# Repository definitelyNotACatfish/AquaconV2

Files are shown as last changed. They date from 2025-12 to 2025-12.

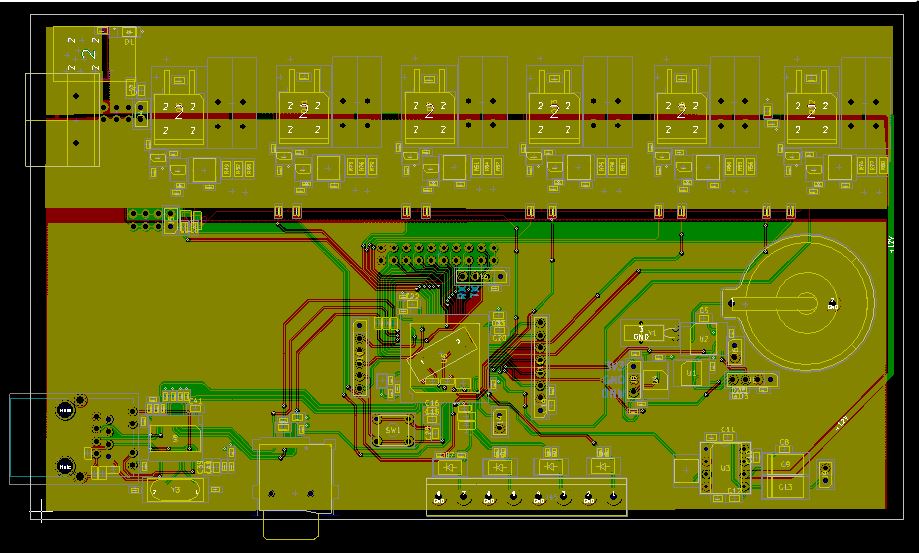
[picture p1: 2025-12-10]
SDCard/WEBSERV/PICTURE/WEBSERV.JPG

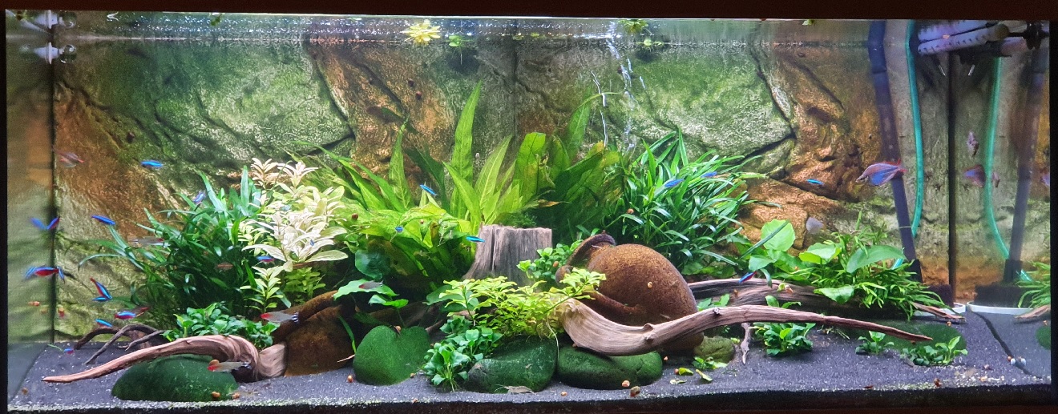
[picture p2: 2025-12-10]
SDCard/WEBSERV/PICTURE/AQUARIUM.JPG

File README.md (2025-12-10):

# Web based Aquarium LED controller
I didn't want to pay 200€ to buy a 6 channel LED PWM controller. So I invested 400€ and a half year to build it myself :)

## Keyfeatures
- 6 channels PWM controlled (For LEDs and other stuff like CO2 relay or PC fan to cool water surface
- Web based interface to set up channel independent scenarious
- Temperature controlled water surface cooling (Really cool in summer)
- SD card bootloader and ethernet based file transfer to SD card

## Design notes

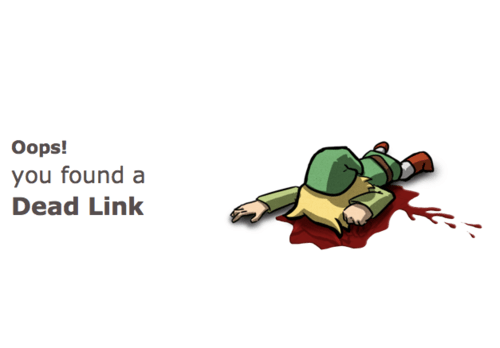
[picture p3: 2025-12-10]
SDCard/WEBSERV/PICTURE/DEADLINK.PNG

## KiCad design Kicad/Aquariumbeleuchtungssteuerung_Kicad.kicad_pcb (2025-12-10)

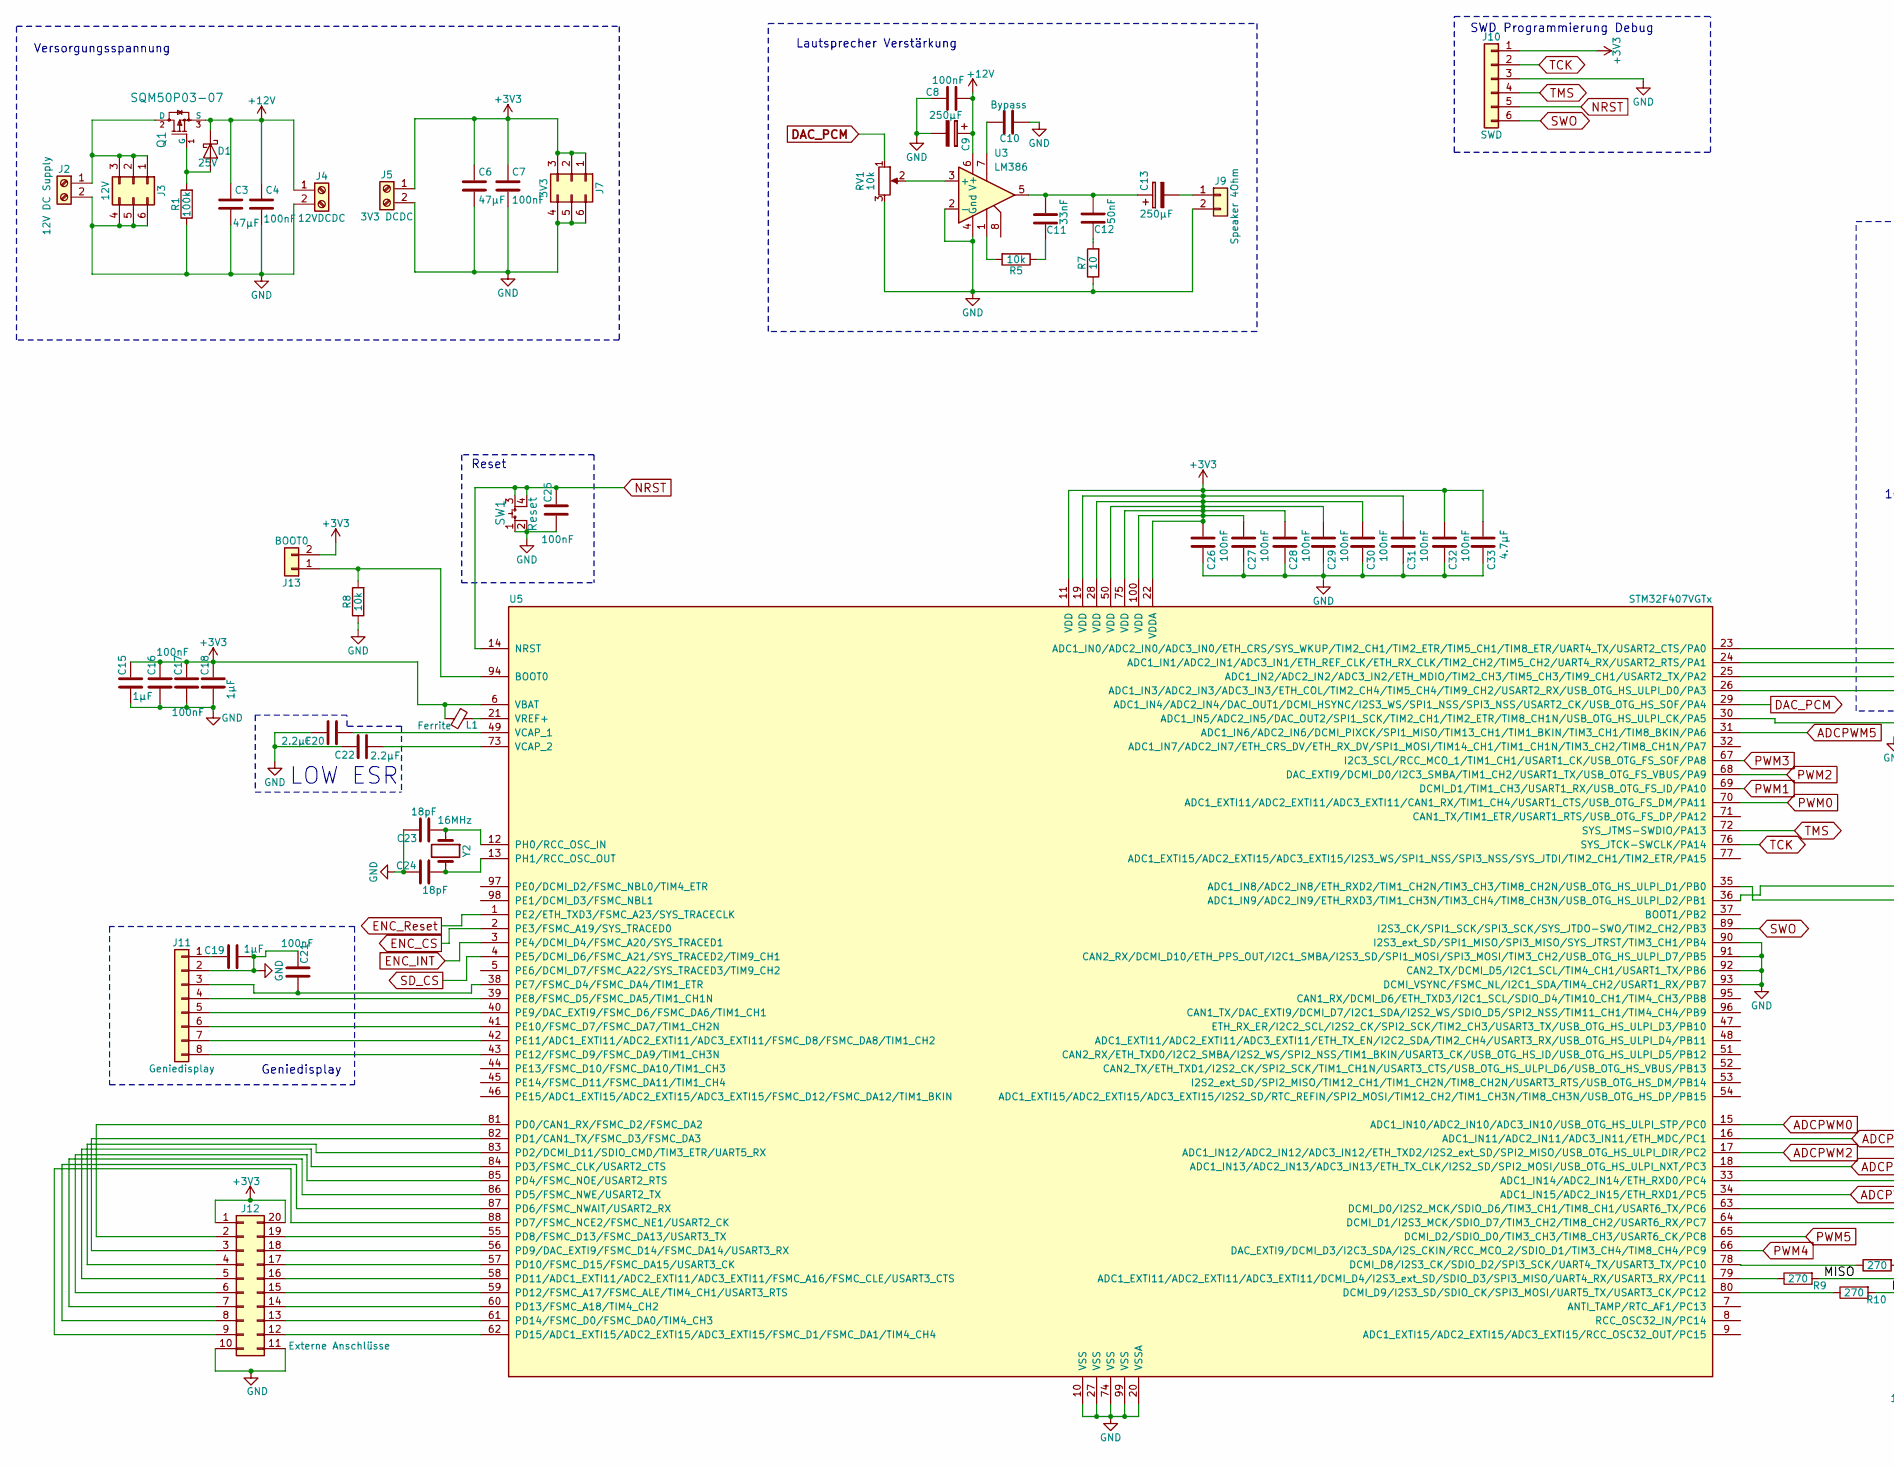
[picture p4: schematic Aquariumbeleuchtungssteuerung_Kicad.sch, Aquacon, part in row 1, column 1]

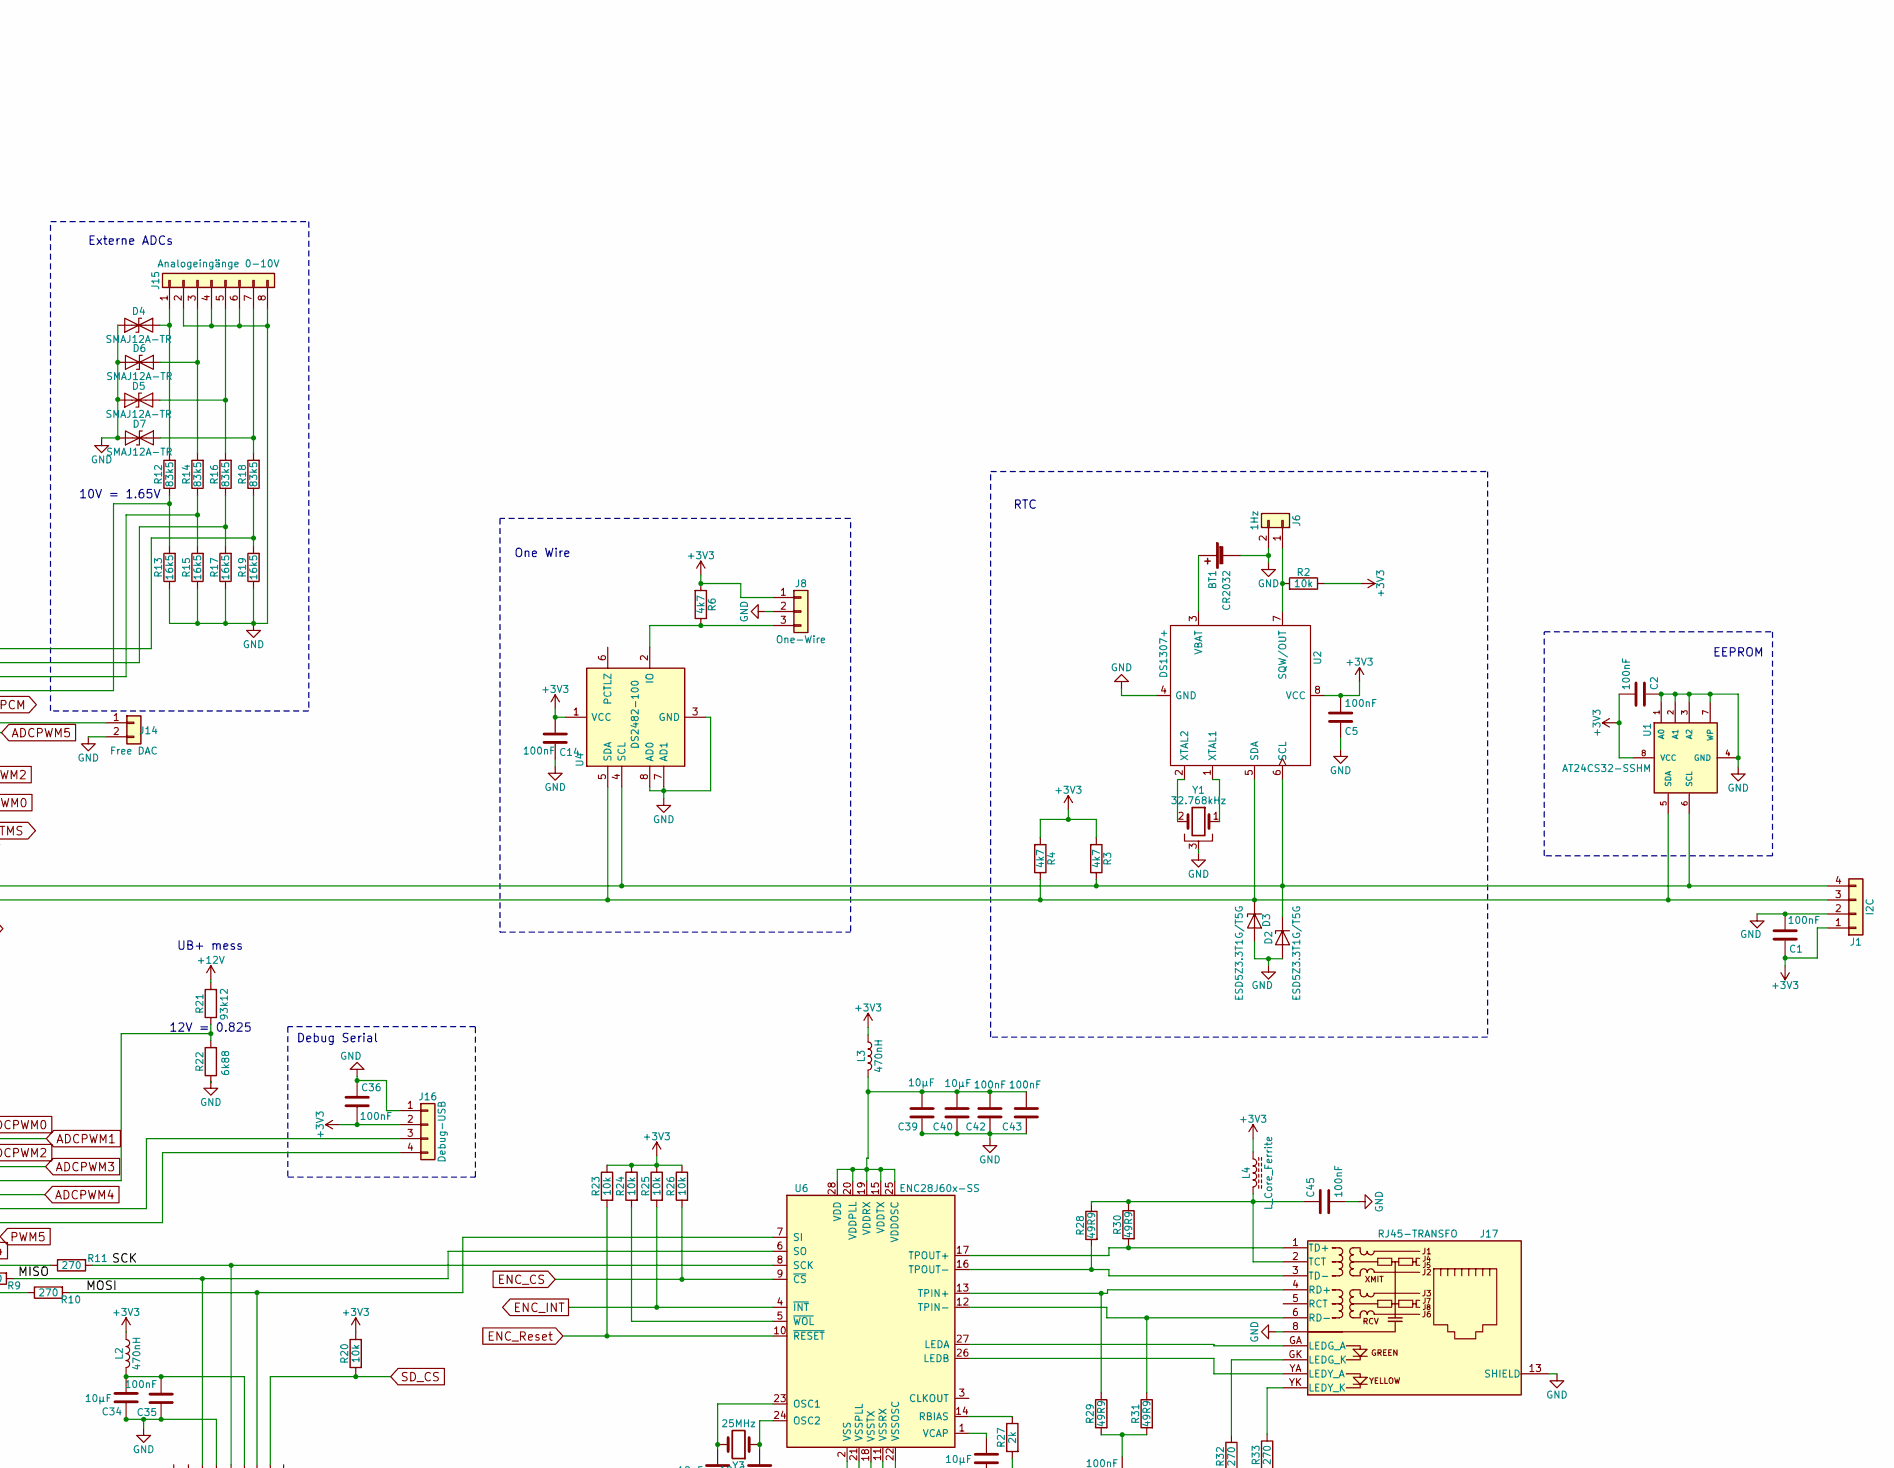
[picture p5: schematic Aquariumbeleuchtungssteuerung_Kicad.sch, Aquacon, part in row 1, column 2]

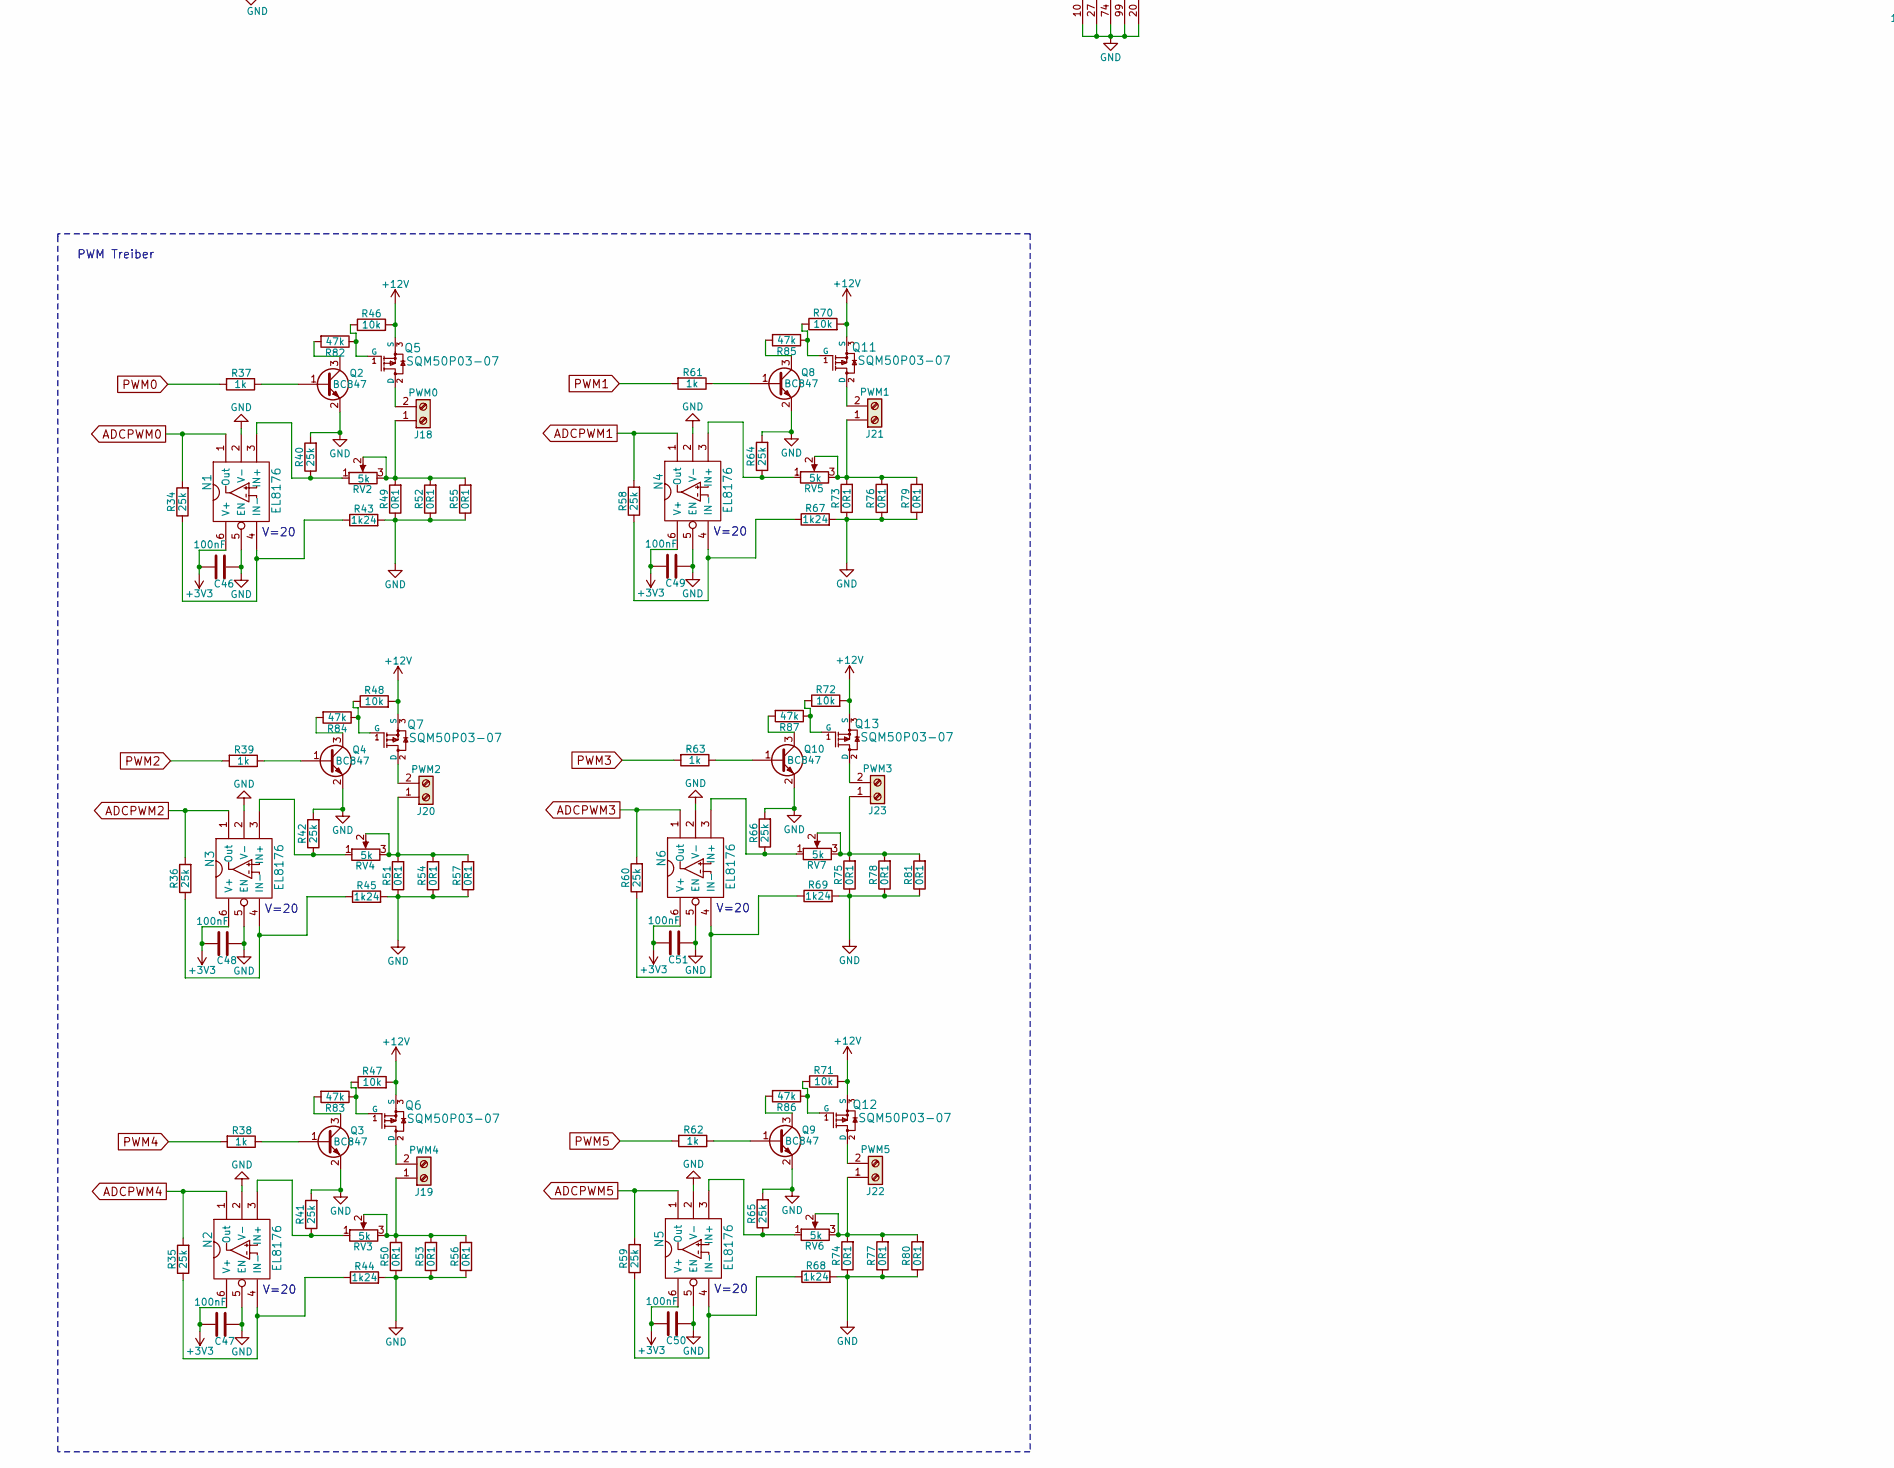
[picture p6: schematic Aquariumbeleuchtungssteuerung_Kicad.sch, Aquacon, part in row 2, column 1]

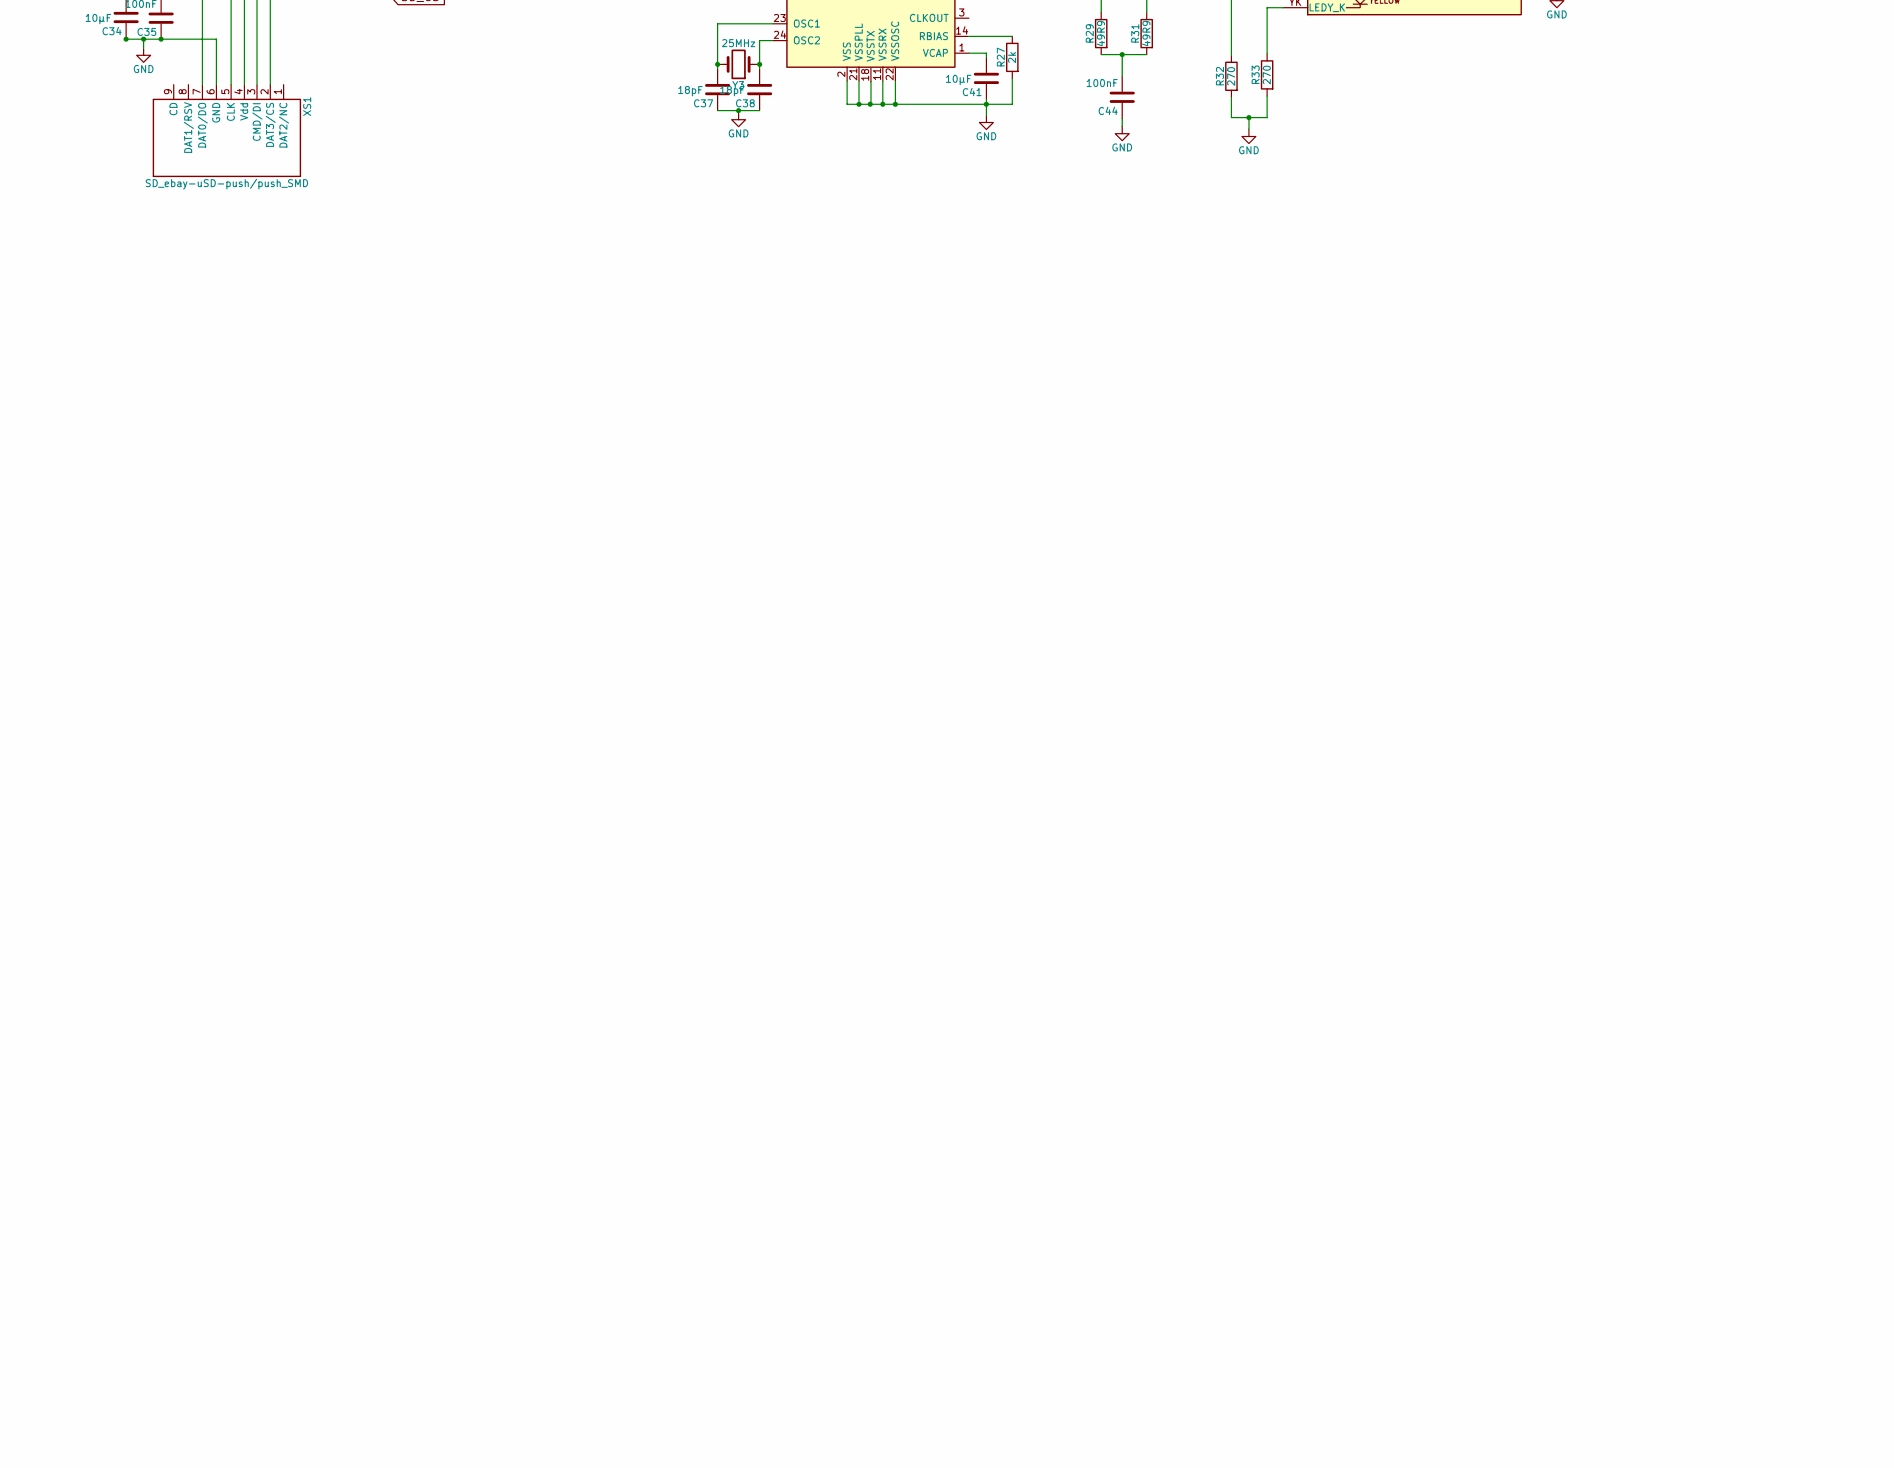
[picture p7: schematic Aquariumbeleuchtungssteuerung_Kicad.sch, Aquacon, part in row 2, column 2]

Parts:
BT1: CR2032; Keystone_105_1x2430-CoinCell
C1, C2, C14, C21, C26, C27, C28, C29, C30, C31, C32, C36, C42, C43, C44, C45, C46, C47, C48, C49, C50, C51: 100nF; C_0603
C3, C6: 47µF; R_1206
C4, C5, C7, C8, C16, C17, C25: 100nF; C_0805
C9, C13: 250µF; CP_Tantalum_Case-X_EIA-7343-43_Reflow
C10: Bypass; C_0805
C11: 33nF; C_0805
C12: 50nF; C_0805
C15, C18, C19: 1µF; C_0805
C20, C22: 2.2µF; C_0805
C23, C24, C37, C38: 18pF; C_0603
C33: 4.7µF; C_0805
C34: 10µF; L_0805
C35: 100nF; L_0603
C39, C40, C41: 10µF; C_0805
D1: 25V; D_SOD-123
D2, D3: ESD5Z3.3T1G/T5G; D_SOD-523
D4, D5, D6, D7: SMAJ12A-TR; D_SMA
J1: I2C; Pin_Header_Straight_1x04_Pitch2.54mm
J2: 12V DC Supply; DECA_MB91_9.52mm_01X02
J3: 12V; Stiftleiste-2x3x2.54mm
J4: 12VDCDC; Pin_Header_Straight_1x02_Pitch2.54mm
J5: 3V3 DCDC; Pin_Header_Straight_1x02_Pitch2.54mm
J6: 1Hz; Pin_Header_Straight_1x02_Pitch2.54mm
J7: 3V3; Stiftleiste-2x3x2.54mm
J8: One-Wire; Pin_Header_Straight_1x03_Pitch2.54mm
J9: Speaker 4Ohm; Pin_Header_Straight_1x02_Pitch2.54mm
J10: SWD; Pin_Header_Straight_1x06_Pitch2.54mm
J11: Geniedisplay; Pin_Header_Straight_1x08_Pitch2.54mm
J12: Externe Anschlüsse; Stiftleiste_02x10
J13: BOOT0; GS2
J14: Free DAC; Pin_Header_Straight_1x02_Pitch2.54mm
J15: Analogeingänge 0-10V; TerminalBlock_bornier-8_P5.08mm
J16: Debug-USB; Pin_Header_Straight_1x04_Pitch2.54mm
J17: RJ45-TRANSFO; RJ45_TRANSFO
J18: PWM0; Phoenix-D-FRONT-2.5Vx2
J19: PWM4; Phoenix-D-FRONT-2.5Vx2
J20: PWM2; Phoenix-D-FRONT-2.5Vx2
J21: PWM1; Phoenix-D-FRONT-2.5Vx2
J22: PWM5; Phoenix-D-FRONT-2.5Vx2
J23: PWM3; Phoenix-D-FRONT-2.5Vx2
L1: Ferrite; L_0805
L2: 470nH; L_0805
L3: 470nH; L_0603
L4: L_Core_Ferrite; L_0603
N1, N2, N3, N4, N5, N6: EL8176; SOT-23-6_Handsoldering
Q1, Q5, Q6, Q7, Q11, Q12, Q13: SQM50P03-07; TO-263-2
Q2, Q3, Q4, Q8, Q9, Q10: BC847; SOT-23
R1: 100k; R_0805
R2, R8, R20, R23, R24, R25, R26: 10k; R_0603
R3, R4, R6: 4k7; R_0603
R5, R46, R47, R48, R70, R71, R72: 10k; R_0805
R7: 10; R_0805
R9, R10, R11, R32, R33: 270; R_0603
R12, R14, R16, R18: 83k5; R_0603
R13, R15, R17, R19: 16k5; R_0603
R21: 93k12; R_0805
R22: 6k88; R_0805
R27: 2k; R_0603
R28, R29, R30, R31: 49R9; R_0603
R34, R35, R36, R40, R41, R42, R58, R59, R60, R64, R65, R66: 25k; R_0603
R37, R38, R39, R61, R62, R63: 1k; R_0603
R43, R44, R45, R67, R68, R69: 1k24; R_0603
R49, R50, R51, R52, R53, R54, R55, R56, R57, R73, R74, R75, R76, R77, R78, R79, R80, R81: 0R1; R_1206
R82, R83, R84, R85, R86, R87: 47k; R_0603
RV1: 10k; Potentiometer_Trimmer_Bourns_3224J
RV2, RV3, RV4, RV5, RV6, RV7: 5k; Potentiometer_Trimmer_Bourns_3224J
SW1: Reset; SW_TH_Tactile_Omron_B3F-10xx
U1: AT24CS32-SSHM; SOIC-8_3.9x4.9mm_Pitch1.27mm
U2: DS1307+; SO-8_5.3x6.2mm_Pitch1.27mm
U3: LM386; DIP-8_W7.62mm_Socket
U4: DS2482-100; SOIC-8_3.9x4.9mm_Pitch1.27mm
U5: STM32F407VGTx; LQFP-100_14x14mm_Pitch0.5mm
U6: ENC28J60x-SS; SSOP-28_5.3x10.2mm_Pitch0.65mm
XS1: SD_ebay-uSD-push/push_SMD; Conn_uSDcard
Y1: 32.768kHz; Crystal_C38-LF_d3.0mm_l8.0mm_Horizontal_1EP_style2
Y2: 16MHz; Crystal_SMD_HC49-SD
Y3: 25MHz; Crystal_SMD_HC49-SD

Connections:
+3V3: C1.1, C2.2, C5.2, C6.1, C7.1, C14.2, C15.1, C16.1, C17.1, C18.1, C26.2, C27.2, C28.2, C29.2, C30.2, C31.2, C32.2, C33.2, C36.2, C46.2, C47.2, C48.2, C49.2, C50.2, C51.2, J1.1, J5.1, J7.1, J7.2, J7.3, J8.1, J10.1, J12.1, J12.20, J13.2, J16.2, L1.2, L2.1, L3.1, L4.1, N1.6 (V+), N2.6 (V+), N3.6 (V+), N4.6 (V+), N5.6 (V+), N6.6 (V+), R2.1, R3.2, R4.2, R6.2, R20.1, R23.1, R24.1, R25.1, R26.1, U1.8 (VCC), U2.8 (VCC), U4.1 (VCC), U5.6 (VBAT), U5.11 (VDD), U5.19 (VDD), U5.22 (VDDA), U5.28 (VDD), U5.50 (VDD), U5.75 (VDD), U5.100 (VDD)
+12V: C3.1, C4.1, C8.1, C9.1, D1.1 (K), J4.1, Q1.3 (S), Q5.3 (S), Q6.3 (S), Q7.3 (S), Q11.3 (S), Q12.3 (S), Q13.3 (S), R21.2, R46.2, R47.2, R48.2, R70.2, R71.2, R72.2, U3.6 (V+)
/MISO: R9.2, U6.6 (SO), XS1.7 (DAT0/DO)
/MOSI: R10.2, U6.7 (SI), XS1.3 (CMD/DI)
/SCK: R11.2, U6.8 (SCK), XS1.5 (CLK)
ADCPWM0: N1.1 (Out), R34.2, U5.15 (ADC1_IN10/ADC2_IN10/ADC3_IN10/USB_OTG_H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)
ADCPWM1: N4.1 (Out), R58.2, U5.16 (ADC1_IN11/ADC2_IN11/ADC3_IN11/ETH_MDC/P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)
ADCPWM2: N3.1 (Out), R36.2, U5.17 (ADC1_IN12/ADC2_IN12/ADC3_IN12/ETH_TXD2/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)
ADCPWM3: N6.1 (Out), R60.2, U5.18 (ADC1_IN13/ADC2_IN13/ADC3_IN13/ETH_TX_CL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)
ADCPWM4: N2.1 (Out), R35.2, U5.34 (ADC1_IN15/ADC2_IN15/ETH_RXD1/PC5)
ADCPWM5: N5.1 (Out), R59.2, U5.31 (ADC1_IN6/ADC2_IN6/DCMI_PIXCK/SPI1_MISO/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)
DAC_PCM: RV1.1, U5.29 (ADC1_IN4/ADC2_IN4/DAC_OUT1/DCMI_HSYNC/I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)
ENC_CS: R26.2, U5.2 (PE3/FSMC_A19/SYS_TRACED0), U6.9 (~CS)
ENC_INT: R25.2, U5.3 (PE4/DCMI_D4/FSMC_A20/SYS_TRACED1), U6.4 (~INT)
ENC_Reset: R23.2, U5.1 (PE2/ETH_TXD3/FSMC_A23/SYS_TRACECLK), U6.10 (~RESET)
GND: BT1.2 (-), C1.2, C2.1, C3.2, C4.2, C5.1, C6.2, C7.2, C8.2, C9.2, C10.2, C14.1, C15.2, C16.2, C17.2, C18.2, C19.2, C20.1, C21.1, C22.1, C23.1, C24.1, C25.2, C26.1, C27.1, C28.1, C29.1, C30.1, C31.1, C32.1, C33.1, C34.1, C35.1, C36.1, C37.1, C38.1, C39.1, C40.1, C41.1, C42.1, C43.1, C44.1, C45.2, C46.1, C47.1, C48.1, C49.1, C50.1, C51.1, D2.2 (A), D3.2 (A), D4.1 (A1), D5.1 (A1), D6.1 (A1), D7.1 (A1), J1.2, J2.2, J3.4, J3.5, J3.6, J4.2, J5.2, J6.2, J7.4, J7.5, J7.6, J8.2, J9.2, J10.3, J11.2, J12.10, J12.11, J14.2, J15.2, J15.4, J15.6, J15.8, J16.1, J17.8, J17.13 (SHIELD), N1.2 (V-), N1.5 (EN), N2.2 (V-), N2.5 (EN), N3.2 (V-), N3.5 (EN), N4.2 (V-), N4.5 (EN), N5.2 (V-), N5.5 (EN), N6.2 (V-), N6.5 (EN), Q2.2 (E), Q3.2 (E), Q4.2 (E), Q8.2 (E), Q9.2 (E), Q10.2 (E), R1.1, R7.1, R8.1, R13.1, R15.1, R17.1, R19.1, R22.1, R27.2, R32.2, R33.2, R40.2, R41.2, R42.2, R43.2, R44.2, R45.2, R49.1, R50.1, R51.1, R52.1, R53.1, R54.1, R55.1, R56.1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
NRST: C25.1, J10.5, SW1.3, SW1.4, U5.14 (NRST)
unnamed: BT1.1 (+), U2.3 (VBAT)
unnamed: C10.1, U3.7
unnamed: C11.1, R5.1
unnamed: C11.2, C12.2, C13.1, U3.5
unnamed: C12.1, R7.2
unnamed: C13.2, J9.1
unnamed: C19.1, J11.1
unnamed: C20.2, U5.49 (VCAP_1)
unnamed: C21.2, J11.3, U5.38 (PE7/FSMC_D4/FSMC_DA4/TIM1_ETR)
unnamed: C22.2, U5.73 (VCAP_2)
unnamed: C23.2, U5.12 (PH0/RCC_OSC_IN), Y2.1
unnamed: C24.2, U5.13 (PH1/RCC_OSC_OUT), Y2.2
unnamed: C34.2, C35.2, L2.2, XS1.4 (Vdd)
unnamed: C37.2, U6.23 (OSC1), Y3.2
unnamed: C38.2, U6.24 (OSC2), Y3.1
unnamed: C39.2, C40.2, C42.2, C43.2, L3.2, U6.15 (VDDTX), U6.19 (VDDRX), U6.20 (VDDPLL), U6.25 (VDDOSC), U6.28 (VDD)
unnamed: C41.2, U6.1 (VCAP)
unnamed: C44.2, R29.2, R31.2
unnamed: C45.1, J17.2 (TCT), L4.2, R28.1, R30.1
unnamed: D1.2 (A), Q1.1 (G), R1.2
unnamed: D2.1 (K), J1.4, R3.1, U1.6 (SCL), U2.6 (SCL), U4.4 (SCL), U5.36 (ADC1_IN9/ADC2_IN9/ETH_RXD3/TIM1_CH3N/TI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)
unnamed: D3.1 (K), J1.3, R4.1, U1.5 (SDA), U2.5 (SDA), U4.5 (SDA), U5.35 (ADC1_IN8/ADC2_IN8/ETH_RXD2/TIM1_CH2N/TI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)
unnamed: D4.2 (A2), J15.1, R12.2
unnamed: D5.2 (A2), J15.5, R16.2
unnamed: D6.2 (A2), J15.3, R14.2
unnamed: D7.2 (A2), J15.7, R18.2
unnamed: J2.1, J3.1, J3.2, J3.3, Q1.2 (D)
unnamed: J6.1, R2.2, U2.7 (SQW/OUT)
unnamed: J8.3, R6.1, U4.2 (IO)
unnamed: J11.4, U5.39 (PE8/FSMC_D5/FSMC_DA5/TIM1_CH1N)
unnamed: J11.5, U5.40 (PE9/DAC_EXTI9/FSMC_D6/FSMC_DA6/TIM1_CH1)
unnamed: J11.6, U5.41 (PE10/FSMC_D7/FSMC_DA7/TIM1_CH2N)
unnamed: J11.7, U5.42 (PE11/ADC1_EXTI11/ADC2_EXTI11/ADC3_EXTI1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)
unnamed: J11.8, U5.43 (PE12/FSMC_D9/FSMC_DA9/TIM1_CH3N)
unnamed: J12.2, U5.81 (PD0/CAN1_RX/FSMC_D2/FSMC_DA2)
unnamed: J12.3, U5.82 (PD1/CAN1_TX/FSMC_D3/FSMC_DA3)
unnamed: J12.4, U5.83 (PD2/DCMI_D11/SDIO_CMD/TIM3_ETR/UART5_RX)
unnamed: J12.5, U5.84 (PD3/FSMC_CLK/USART2_CTS)
unnamed: J12.6, U5.85 (PD4/FSMC_NOE/USART2_RTS)
unnamed: J12.7, U5.86 (PD5/FSMC_NWE/USART2_TX)
unnamed: J12.8, U5.87 (PD6/FSMC_NWAIT/USART2_RX)
unnamed: J12.9, U5.88 (PD7/FSMC_NCE2/FSMC_NE1/USART2_CK)
unnamed: J12.12, U5.62 (PD15/ADC1_EXTI15/ADC2_EXTI15/ADC3_EXTI1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)
unnamed: J12.13, U5.61 (PD14/FSMC_D0/FSMC_DA0/TIM4_CH3)
unnamed: J12.14, U5.60 (PD13/FSMC_A18/TIM4_CH2)
unnamed: J12.15, U5.59 (PD12/FSMC_A17/FSMC_ALE/TIM4_CH1/USART3_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)
unnamed: J12.16, U5.58 (PD11/ADC1_EXTI11/ADC2_EXTI11/ADC3_EXTI1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)
unnamed: J12.17, U5.57 (PD10/FSMC_D15/FSMC_DA15/USART3_CK)
unnamed: J12.18, U5.56 (PD9/DAC_EXTI9/FSMC_D14/FSMC_DA14/USART3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)
unnamed: J12.19, U5.55 (PD8/FSMC_D13/FSMC_DA13/USART3_TX)
unnamed: J13.1, R8.2, U5.94 (BOOT0)
unnamed: J14.1, U5.30 (ADC1_IN5/ADC2_IN5/DAC_OUT2/SPI1_SCK/TIM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)
unnamed: J16.3, U5.63 (DCMI_D0/I2S2_MCK/SDIO_D6/TIM3_CH1/TIM8_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)
unnamed: J16.4, U5.64 (DCMI_D1/I2S3_MCK/SDIO_D7/TIM3_CH2/TIM8_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)
unnamed: J17.1 (TD+), R30.2, U6.17 (TPOUT+)
unnamed: J17.3 (TD-), R28.2, U6.16 (TPOUT-)
unnamed: J17.4 (RD+), R29.1, U6.13 (TPIN+)
unnamed: J17.6 (RD-), R31.1, U6.12 (TPIN-)
unnamed: J17.GA (LEDG_A), U6.27 (LEDA)
unnamed: J17.GK (LEDG_K), R32.1
unnamed: J17.YA (LEDY_A), U6.26 (LEDB)
unnamed: J17.YK (LEDY_K), R33.1
unnamed: J18.1, R49.2, R52.2, R55.2, RV2.2, RV2.3
unnamed: J18.2, Q5.2 (D)
unnamed: J19.1, R50.2, R53.2, R56.2, RV3.2, RV3.3
unnamed: J19.2, Q6.2 (D)
unnamed: J20.1, R51.2, R54.2, R57.2, RV4.2, RV4.3
unnamed: J20.2, Q7.2 (D)
unnamed: J21.1, R73.2, R76.2, R79.2, RV5.2, RV5.3
unnamed: J21.2, Q11.2 (D)
unnamed: J22.1, R74.2, R77.2, R80.2, RV6.2, RV6.3
unnamed: J22.2, Q12.2 (D)
unnamed: J23.1, R75.2, R78.2, R81.2, RV7.2, RV7.3
unnamed: J23.2, Q13.2 (D)
unnamed: L1.1, U5.21 (VREF+)
unnamed: N1.3 (IN+), R40.1, RV2.1
unnamed: N1.4 (IN-), R34.1, R43.1
unnamed: N2.3 (IN+), R41.1, RV3.1
unnamed: N2.4 (IN-), R35.1, R44.1
unnamed: N3.3 (IN+), R42.1, RV4.1
unnamed: N3.4 (IN-), R36.1, R45.1
unnamed: N4.3 (IN+), R64.1, RV5.1
unnamed: N4.4 (IN-), R58.1, R67.1
unnamed: N5.3 (IN+), R65.1, RV6.1
unnamed: N5.4 (IN-), R59.1, R68.1
unnamed: N6.3 (IN+), R66.1, RV7.1
unnamed: N6.4 (IN-), R60.1, R69.1
unnamed: Q2.1 (B), R37.1
unnamed: Q2.3 (C), R82.2
unnamed: Q3.1 (B), R38.1
unnamed: Q3.3 (C), R83.2
unnamed: Q4.1 (B), R39.1
unnamed: Q4.3 (C), R84.2
unnamed: Q5.1 (G), R46.1, R82.1
unnamed: Q6.1 (G), R47.1, R83.1
unnamed: Q7.1 (G), R48.1, R84.1
unnamed: Q8.1 (B), R61.1
unnamed: Q8.3 (C), R85.2
unnamed: Q9.1 (B), R62.1
unnamed: Q9.3 (C), R86.2
unnamed: Q10.1 (B), R63.1
unnamed: Q10.3 (C), R87.2
unnamed: Q11.1 (G), R70.1, R85.1
unnamed: Q12.1 (G), R71.1, R86.1
unnamed: Q13.1 (G), R72.1, R87.1
unnamed: R5.2, U3.1
unnamed: R9.1, U5.79 (ADC1_EXTI11/ADC2_EXTI11/ADC3_EXTI11/DCM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)
unnamed: R10.1, U5.80 (DCMI_D9/I2S3_SD/SDIO_CK/SPI3_MOSI/UART5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)
unnamed: R11.1, U5.78 (DCMI_D8/I2S3_CK/SDIO_D2/SPI3_SCK/UART4_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)
unnamed: R12.1, R13.2, U5.26 (ADC1_IN3/ADC2_IN3/ADC3_IN3/ETH_COL/TIM2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)
unnamed: R14.1, R15.2, U5.25 (ADC1_IN2/ADC2_IN2/ADC3_IN2/ETH_MDIO/TIM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)
unnamed: R16.1, R17.2, U5.24 (ADC1_IN1/ADC2_IN1/ADC3_IN1/ETH_REF_CLK/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)
unnamed: R18.1, R19.2, U5.23 (ADC1_IN0/ADC2_IN0/ADC3_IN0/ETH_CRS/SYS_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)
unnamed: R21.1, R22.2, U5.33 (ADC1_IN14/ADC2_IN14/ETH_RXD0/PC4)
unnamed: R24.2, U6.5 (~WOL)
unnamed: R27.1, U6.14 (RBIAS)
unnamed: RV1.2, U3.3 (+)
unnamed: U2.1 (XTAL1), Y1.1
unnamed: U2.2 (XTAL2), Y1.2
PWM0: R37.2, U5.70 (ADC1_EXTI11/ADC2_EXTI11/ADC3_EXTI11/CAN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)
PWM1: R61.2, U5.69 (DCMI_D1/TIM1_CH3/USART1_RX/USB_OTG_FS_I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)
PWM2: R39.2, U5.68 (DAC_EXTI9/DCMI_D0/I2C3_SMBA/TIM1_CH2/US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)
PWM3: R63.2, U5.67 (I2C3_SCL/RCC_MCO_1/TIM1_CH1/USART1_CK/U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)
PWM4: R38.2, U5.66 (DAC_EXTI9/DCMI_D3/I2C3_SDA/I2S_CKIN/RCC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)
PWM5: R62.2, U5.65 (DCMI_D2/SDIO_D0/TIM3_CH3/TIM8_CH3/USART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)
SD_CS: R20.2, U5.4 (PE5/DCMI_D6/FSMC_A21/SYS_TRACED2/TIM9_C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), XS1.2 (DAT3/CS)
SWO: J10.6, U5.89 (I2S3_CK/SPI1_SCK/SPI3_SCK/SYS_JTDO-SWO/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)
TCK: J10.2, U5.76 (SYS_JTCK-SWCLK/PA14)
TMS: J10.4, U5.72 (SYS_JTMS-SWDIO/PA13)

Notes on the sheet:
12V = 0.825
UB+ mess
10V = 1.65V
PWM Treiber
Versorgungsspannung
V=20
Lautsprecher Verstärkung
V=20
Debug Serial
One Wire
RTC
EEPROM
LOW ESR
Reset
SWD Programmierung Debug
Geniedisplay
Externe ADCs

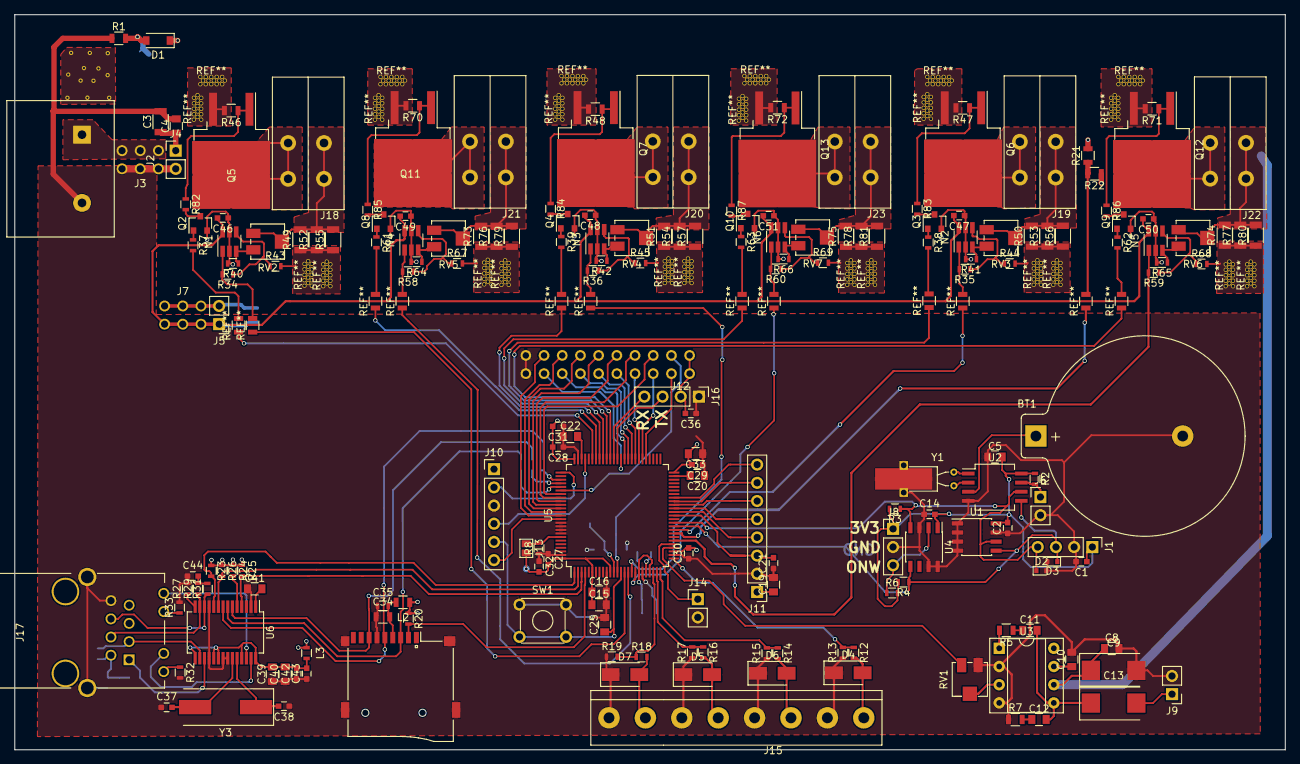
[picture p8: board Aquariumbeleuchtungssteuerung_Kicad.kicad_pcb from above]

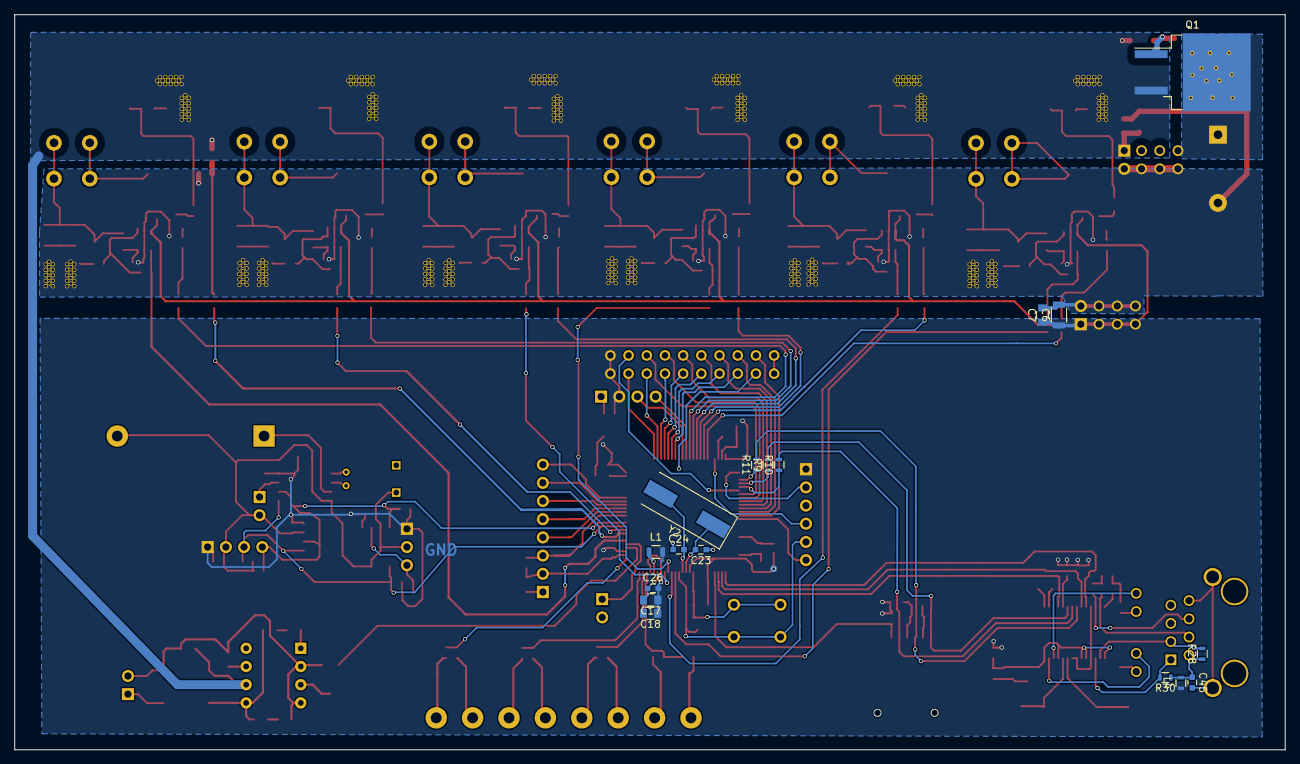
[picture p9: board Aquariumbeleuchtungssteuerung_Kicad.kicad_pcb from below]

Board: 2 copper layers, 177.4 x 102.6 mm, 210 parts (17 on the bottom side), 146 nets.

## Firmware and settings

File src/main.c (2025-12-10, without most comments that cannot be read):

// Includes
#include "main.h"
#include <stdio.h>
#include <string.h>
#include <stdlib.h>
#include "time.h"
#include <stm32f4xx.h>
#include <stdint.h>
#include "USART.h"
#include "SoftwareI2C.h"
#include "SPI.h"
#include "DS1307.h"
#include "SD.h"
#include "FAT32.h"
#include "ENC28J60.h"
#include "Stack.h"
#include "Tasktimer.h"
#include "DHCP.h"
#include "NTP.h"
#include "HTTP.h"
#include "FTP.h"
#include "Geniedisplay.h"
#include "Debug.h"
#include "WAV.h"
#include "PWM.h"
#include "weather.h"
#include "ADC.h"
#include "Power.h"
#include "DS18B20.h"
#include "AT24C32.h"
#include "DS2482_100.h"
#include "INI_Parser.h"
#include "FirmwareUpdater.h"

/*

************************************************************************************************
* AquaconV2 auf dem STM32F407VGT6															   *
* 19.02.2019 � Frederinn															   *
************************************************************************************************

*/

#if TempLog_Temp_Filenumber < TCP_Max_Entries || TempLog_Temp_Filenumber > FAT32_Max_Entries
	#error "Die Temp-Datei darf nicht im Bereich der TCP Dateien liegen"
#endif
#if TempLog_Label_Filenumber < TCP_Max_Entries || TempLog_Label_Filenumber > FAT32_Max_Entries
	#error "Die Label-Datei darf nicht im Bereich der TCP Dateien liegen"
#endif
#if Weather_Filenumber < TCP_Max_Entries || Weather_Filenumber > FAT32_Max_Entries
	#error "Die Wetter-Datei darf nicht im Bereich der TCP Dateien liegen"
#endif
#if Weather_Temp_Filenumber < TCP_Max_Entries || Weather_Temp_Filenumber > FAT32_Max_Entries
	#error "Die Wettertemperatur-Datei darf nicht im Bereich der TCP Dateien liegen"
#endif
#if INI_Parser_Read_Filenumber < TCP_Max_Entries || INI_Parser_Read_Filenumber > FAT32_Max_Entries
	#error "Die INI-Parser-Datei darf nicht im Bereich der TCP Dateien liegen"
#endif
#if INI_Parser_Write_Filenumber < TCP_Max_Entries || INI_Parser_Write_Filenumber > FAT32_Max_Entries
	#error "Die INI-Parser-Datei darf nicht im Bereich der TCP Dateien liegen"
#endif
#if WAV_Filenumber < TCP_Max_Entries || WAV_Filenumber > FAT32_Max_Entries
	#error "Die WAV-Datei darf nicht im Bereich der TCP Dateien liegen"
#endif
#if FTP_Filenumber < TCP_Max_Entries || FTP_Filenumber > FAT32_Max_Entries
	#error "Die FTP Hilfsdatei darf nicht im Bereich der TCP Dateien liegen"
#endif
#if FTP_Max_Entries != TCP_Max_Entries || FTP_Max_Entries > FAT32_Max_Entries
	#error "FTP und TCP Tabelle muss gleich gross sein"
#endif
#if ARP_Max_Entries != TCP_Max_Entries
	#error "ARP und TCP Tabelle muss gleich gross sein"
#endif
#if HTTP_Max_Entries != TCP_Max_Entries || HTTP_Max_Entries > FAT32_Max_Entries
	#error "HTTP und TCP Tabelle muss gleich gross sein"
#endif
#if FAT32_Max_Entries < TCP_Max_Entries
	#error "FAT32 Tabelle muss groesser oder gleich TCP Tabelle sein"
#endif
#if TCP_MSS < 405
	#error "TCP_MSS muss groesser als 405 Bytes sein"
#endif
#if TCP_Window < 405
	#error "TCP_Window muss groesser als 405 Bytes sein"
#endif
#if Parser_min_MSS > TCP_MSS || Parser_min_MSS > TCP_Window
	#error "TCP_Window und TCP_MSS muessen groesser als Parser_min_MSS sein, sonst funktioniert das Parsen nicht"
#endif
#if ARP_Max_Entries >= 255
	#error "ARP Tabelle muss kleiner 255 Eintr�ge sein"
#endif
#if TCP_Max_Entries >= 255
	#error "TCP Tabelle muss kleiner 255 Eintr�ge sein"
#endif


// Variablen
struct Webserver gl_Webserver;													// Globale von Webserver

// Funktionen
int main(void)
{
	__enable_irq();																// IRQs nach Bootloader wieder aktivieren

	// PLL einstellen mit internem 16MHz Quarz auf 102MHz
	if(!((RCC->CFGR & 0x0000000c)==4)) 											// Wenn HSI16 nicht eingeschaltet ist, dann mach das mal
	{
		RCC->CR |= (1<<0);														// Schalte den HSI16 an
		while(!((RCC->CR & 0x00000002)==0b10));
		RCC->CFGR &= 0xfffffffc;												// Setze die HSI16 als Systemclock
		while(!((RCC->CFGR & 0x0000000c)==0b0000));
		RCC->CR &= ~(1<<24);													// PLL auschalten
		while((RCC->CR & 0x02000000) == 0x02000000); 							// Warte bis die PLL steht
		FLASH->ACR |= FLASH_ACR_LATENCY_3WS;									// Latenz auf 3 (90 < F_CPU <= 120)
		RCC->PLLCFGR = 0b00000000000000000110011000100000; 						// PLLP auf 2, PLLN auf 408, PLLM auf 32 -> 16MHz HSI auf 102MHz
		RCC->CR &= ~(1<<16);													// PLLSRC auf 0 = HSI16 Source
		RCC->CR |= (1<<24);														// PLL anschalten
		while(!((RCC->CR & 0x02000000) == 0x02000000));
		RCC->CFGR |= (1<<1);													// Setze die PLL
		while(!((RCC->CFGR & 0x0000000c)==0b1000));
	}

	_delay_us_init(250000);														// Delay 250ms nach Systemstart

	USART_Init(256000UL);
	Genie_Init();

	SD_Portinit();																// SD Portinit
	SPI_Portinit();																// SPI Portinit

	uint8_t SD_Init_result=0;
	if(SD_Card_mount()==0)														// SD Karte einbinden
	{
		SD_Init_result=1;
		Genie_Write_String_5_7(0,0,"SD Init OK");
	}
	else
	{
		Genie_Write_String_5_7(0,0,"SD Init FEHLER");
	}

	// PLL einstellen mit internem 16MHz Quarz auf 168MHz
	RCC->CR |= (1<<0);															// Schalte den HSI16 an
	while(!((RCC->CR & 0x00000002)==0b10));
	RCC->CFGR &= 0xfffffffc;													// Setze die HSI16 als Systemclock
	while(!((RCC->CFGR & 0x0000000c)==0b0000));
	RCC->CR &= ~(1<<24);														// PLL auschalten
	while((RCC->CR & 0x02000000) == 0x02000000); 								// Warte bis die PLL steht
	FLASH->ACR |= FLASH_ACR_DCEN | FLASH_ACR_ICEN | FLASH_ACR_LATENCY_4WS;	// Latenz auf 4 und Caches an (F_CPU > 120MHz)
	RCC->PLLCFGR = 0b00000000000000000101010000010000; 							// PLLP auf 2, PLLN auf 336, PLLM auf 16 -> 16MHz HSI auf 168MHz
	RCC->CR &= ~(1<<16);														// PLLSRC auf 0 = HSI16 Source
	RCC->CR |= (1<<24);															// PLL anschalten
	while(!((RCC->CR & 0x02000000) == 0x02000000));
	RCC->CFGR |= (1<<1);														// Setze die PLL
	while(!((RCC->CFGR & 0x0000000c)==0b1000));

	NVIC_SetPriorityGrouping(NVIC_PRIORITYGROUP_4);								// Priogruppe auf 4, 4 Bits preemption, 0 Sub

	SPI_Init(SPI_Clockdiv_default);												// SPI Defaultinit
	uint8_t FAT32_Init_result=0;
	if(SD_Init_result==1)
	{
		if(FAT32_Init()==0)														// Muss zuerst initialisiert werden, dass die basic.INI gelesen werden kann
		{
			FAT32_Init_result=1;
		}
	}

	SoftwareI2C_Master_Init();													// I2C Master Init
	Debug_Command_Init();														// Debug Init, Baud aus I2C EEPROM
	ENC_Portinit();																// ENC Portinit
	PWM_Init();																	// PWM Init
	ADC1_Init();																// ADC1 Init 12Bit
	ADC2_Init();																// ADC2 Init 12Bit

	if(FAT32_Init_result==1)													// In der Debug_Comand_Init wird der Uart konfiguriert
	{
		Genie_Write_String_5_7(0,8,"FAT32 Init OK");
		USART_Write_String("Main: FAT32 Init erfolgreich\r\n");
	}
	else
	{
		Genie_Write_String_5_7(0,8,"FAT32 Init FEHLER");
	}

	if (DS2482_Reset()==0)														// One Wire I2C Bridge
	{
		Genie_Write_String_5_7(0,16,"DS2482-100 Init OK");
		USART_Write_String("Main: DS2482-100 Reset erfolgreich\r\n");
	}
	else
	{
		Genie_Write_String_5_7(0,16,"DS2482-100 Init FEHLER");
	}

	if (DS18B20_Init(&gl_DS18B20,DS18B20_12Bit_resolution,0.00) == 0)			// DS18B20 Init
	{
		Genie_Write_String_5_7(0,24,"DS18B20 Init OK");
		DS18B20_Start_Temperatureconvert(&gl_DS18B20,DS18B20_Match_ROM_true);	// Temperatur messen
	}
	else
	{
		Genie_Write_String_5_7(0,24,"DS18B20 Init FEHLER");
	}

	if (ENC_Init()==0)
	{
		Genie_Write_String_5_7(0,32,"ENC28J60 Init OK");
		USART_Write_String("Main: ENC28J60 Init erfolgreich\r\n");
	}
	else
	{
		Genie_Write_String_5_7(0,32,"ENC28J60 Init FEHLER");
	}

	WAV_Init();																	// WAV Init

	if(DS1307_Init()==0)
	{
		Genie_Write_String_5_7(0,40,"DS1307 Init OK");
		USART_Write_String("Main: DS1307 Init erfolgreich: ");
		USART_Write_String(&gl_Timestamp_String[0]);
	}
	else
	{
		Genie_Write_String_5_7(0,40,"DS1307 Init FEHLER");
	}

	if(DHCP_Init()==0)																			// Muss zuerst sein, fordert IPs von DHCP Server an, ansonsten werden die Werte aus dem EEPROM geladen
	{
		Genie_Write_String_5_7(0,48,"DHCP Init OK");
		USART_Write_String("Main: Netzwerkeinstellungen per DHCP bezogen. Einstellungen aus EEPROM gegebenfalls mitverwendet\r\n");
		printf("Main: DHCP Name: %s\r\n",&gl_DHCP_Cache.Name[0]);
	}
	else
	{
		Genie_Write_String_5_7(0,48,"Netzwerk aus EEPROM");
		USART_Write_String("Main: Netzwerkeinstellungen aus EEPROM geladen\r\n");
	}

	if(NTP_Init()==0)																			// Lade Sommerzeit, Zeitzone und fordere Zeitstempel an; IP wird in der DHCP_Init() ermittelt, Uhrzeit in DS1307 gesetzt
	{
		USART_Write_String("Main: Uhrzeit aus Netzwerk bezogen\r\n");
		Genie_Write_String_5_7(0,56,"NTP Uhrzeit bezogen");
	}
	else
	{
		USART_Write_String("Main: NTP Server nicht erreichbar\r\n");
		Genie_Write_String_5_7(0,56,"NTP nicht erreichbar");
	}

	Main_Init_Tasktimer();																		// Tasktimer wird ganz zum Schluss initialisiert

	HTTP_Init();																				// HTTP Init
	Power_Init();
	Weather_Init();																				// Wettersimulation Init

	FAT32_Directory_Change("/");																// Wechsle zur Root
	WAV_Play_File(WAV_Filenumber,"startup.wav");												// Spiele Startup-Sound
	USART_Write_String("Main: Sytem Hochgefahren\r\n\r\n");

	while (1)
	{
		Stack_Packetloop(0);																	// Paketschleife, Kein ARP Reply Filter
	}
}

void Main_Init_Tasktimer(void)	// 5 und 8 sind wieder frei
{
	DS1307_Read_Timestamp(&gl_Time);																		// Hole einmalig die Systemzeit
	Tasktimer_Add_Task(0,Time_Timestamp_to_UTC(&gl_Time),1,&Main_Read_Timestamp,"RTC");						// Clock lesen

	struct Timestamp temp={gl_Time.Day,gl_Time.Month,gl_Time.Year,gl_Time.Hour,00,00,gl_Time.Weekday};
	Tasktimer_Add_Task(1,Time_Timestamp_to_UTC(&temp)+3600,3600,&NTP_Request_Func_for_Tasktimer,"NTPR");	// NTP Request einmal die Stunde

	if (gl_Tasktimer_Tasks[2].Is_used)																		// Falls der Task in DHCP eingeschaltet wird, muss die Zeit angepasst werden
	{
		Tasktimer_Restart_Task(2,Time_Timestamp_to_UTC(&gl_Time)+gl_DHCP_Cache.Lease,gl_DHCP_Cache.Lease);	// Stelle den Task mit der richtigen Zeit ein
	}

	Tasktimer_Add_Task(3,Time_Timestamp_to_UTC(&gl_Time),TCP_Retransmission_Frequency,&TCP_Retransmittimer,"TCPR");
	Tasktimer_Add_Task(4,Time_Timestamp_to_UTC(&gl_Time),3600,&Tasktimer_Sync_Clock,"Tsyn");				// Einmal die Stunde die Tasktimerclock syncen
	Tasktimer_Add_Task(5,Time_Timestamp_to_UTC(&gl_Time),3600,&Weather_Sync_Tick,"WTck");					// Einmal die Stunde den Weathertick syncen
	Tasktimer_Add_Task(6,Time_Timestamp_to_UTC(&gl_Time),600,&ARP_Clear_Table,"ARPT");						// ARP Tabelle alle 10 Minuten loeschen
	Tasktimer_Add_Task(7,Time_Timestamp_to_UTC(&gl_Time),30,&Main_Genie_refresh,"LCD");						// LCD Text refresh

	Tasktimer_Add_Task(9,Time_Timestamp_to_UTC(&gl_Time),20,&Main_Temperaturelogger,"Temp");				// Beckentemperatur messen

	Tasktimer_Init();																						// Tasktimer Init
}



void Main_Genie_refresh(void)
{
	char Text[22];
	Genie_Clear_Display();
	sprintf(&Text[0],"IP:%u.%u.%u.%u",gl_Webserver.IP_address[0],gl_Webserver.IP_address[1],gl_Webserver.IP_address[2],gl_Webserver.IP_address[3]);
	Genie_Write_String_5_7(0,0,&Text[0]);
	sprintf(&Text[0],"Mask:%u.%u.%u.%u",gl_Webserver.Subnetmask[0],gl_Webserver.Subnetmask[1],gl_Webserver.Subnetmask[2],gl_Webserver.Subnetmask[3]);
	Genie_Write_String_5_7(0,9,&Text[0]);
	sprintf(&Text[0],"Gate:%u.%u.%u.%u",gl_Webserver.Gateway_IP[0],gl_Webserver.Gateway_IP[1],gl_Webserver.Gateway_IP[2],gl_Webserver.Gateway_IP[3]);
	Genie_Write_String_5_7(0,18,Text);
	sprintf(&Text[0],"Becken:%2.2f degC",DS18B20_Read_Temperature(&gl_DS18B20));
	Genie_Write_String_5_7(0,27,Text);
	//sprintf(&Text[0],"NTP:%u.%u.%u.%u",gl_Webserver.NTP_IP[0],gl_Webserver.NTP_IP[1],gl_Webserver.NTP_IP[2],gl_Webserver.NTP_IP[3]);
	//Genie_Write_String_5_7(0,27,Text);
	//Genie_Write_String_5_7(0,36,"DHCP Name:");
	//Genie_Write_String_5_7(0,45,&gl_DHCP_Cache.Name[0]);
	sprintf(&Text[0],"%02u.%02u.%04d %02u:%02u",gl_Time.Day,gl_Time.Month,gl_Time.Year,gl_Time.Hour,gl_Time.Minute);
	Genie_Write_String_5_7(18,56,&Text[0]);
	strcpy(&Text[0],gl_Weekday[gl_Time.Weekday]);
	Text[2] = 0;	// Nur die ersten zwei Buchstaben des Tages verwenden
	Genie_Write_String_5_7(0,56,&Text[0]);
}

void Main_Read_Timestamp(void)
{
	DS1307_Read_Timestamp(&gl_Time);
}

void Main_Temperaturelogger(void)
{
	char buffer[22]={0};
	static uint8_t Day = 1;																// Byte ist statisch

	gl_DS18B20.Temperature = DS18B20_Read_Temperature(&gl_DS18B20);						// Temperatur auslesen
	/*
	FAT32_Directory_Change("/webserv/meassure/");										// Wechsle ins Verzeichnis meassure

	if (gl_Time.Day != Day)
	{
		Day = gl_Time.Day;
		FAT32_File_Delete("labels.txt");
		FAT32_File_Delete("temp.txt");

		FAT32_File_Create("labels.txt",0);												// und neu anlegen
		FAT32_File_Create("temp.txt",0);
	}

	FAT32_File_Open(TempLog_Label_Filenumber, "labels.txt",FAT32_Write);
	FAT32_File_Open(TempLog_Temp_Filenumber, "temp.txt",FAT32_Write);

	sprintf(&buffer[0],"%02u:%02u:%02u,",gl_Time.Hour,gl_Time.Minute,gl_Time.Seconds);	// Schreibe den String
	FAT32_File_Write(TempLog_Label_Filenumber,&buffer[0],strlen(buffer));

	sprintf(&buffer[0],"%2.4f,",gl_DS18B20.Temperature);								// Schreibe den String
	FAT32_File_Write(TempLog_Temp_Filenumber,&buffer[0],strlen(buffer));

	FAT32_File_Close(TempLog_Label_Filenumber);
	FAT32_File_Close(TempLog_Temp_Filenumber);
	*/

	DS18B20_Start_Temperatureconvert(&gl_DS18B20,DS18B20_Match_ROM_true);
}

void Main_Stack_Packetloop_stuff(void)
{
	char buffer[5];
	// USART bearbeitet
	if (gl_USART.Command_arrived)																// Behandle den UART
	{
		gl_USART.Command_arrived=0;
		Debug_Commands();
		USART_Write_String("\r\n\r\n");
		USART_Clear_RX_Buffer();
	}


	if (gl_Time.Day >= 25 && gl_Time.Day <= 31 && gl_Time.Month == 3 && gl_Time.Weekday == 6 && gl_Time.Hour == 2 && gl_NTP_Summertime==0)
	{
		gl_NTP_Summertime=1;
		FAT32_Directory_Change("/");
		sprintf(&buffer[0],"%hhu",gl_NTP_Summertime);																												// Drucke die Variable in den String
		INI_Write_Key_String("weather.ini","Cooling","Used",&buffer[0]);																							// Schreibe den Wert; // Falls nicht per NTP die Zeit bezogen wird muss man den Zeitstempel nicht nach jedem Neustart einstellen
		gl_Time.Hour++;
		DS1307_Set_Timestamp(&gl_Time);
		Main_Init_Tasktimer();
	}
	if (gl_Time.Day >= 25 && gl_Time.Day <= 31 && gl_Time.Month == 10 && gl_Time.Weekday == 6 && gl_Time.Hour == 3 && gl_NTP_Summertime==1)							// Letzer Sonntag im Oktober ist beginn der Winterzeit um 3 Uhr
	{
		gl_NTP_Summertime=0;
		FAT32_Directory_Change("/");
		sprintf(&buffer[0],"%hhu",gl_NTP_Summertime);																												// Drucke die Variable in den String
		INI_Write_Key_String("weather.ini","Cooling","Used",&buffer[0]);																							// Schreibe den Wert; // Falls nicht per NTP die Zeit bezogen wird muss man den Zeitstempel nicht nach jedem Neustart einstellen
		gl_Time.Hour--;
		DS1307_Set_Timestamp(&gl_Time);
		Main_Init_Tasktimer();
	}

	WAV_Read_Filedata();
	Weather_Init_Trigger();

	// Ein Sekunden Task Timer
	Tasktimer_Do_Tasks();																																			// Fuehre die Tasks aus
}

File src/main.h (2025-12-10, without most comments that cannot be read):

#ifndef MAIN_H_
#define MAIN_H_

// Includes
#include <math.h>
#include <stdint.h>

/*

************************************************************************************************
* AquaconV2 auf dem STM32F407VGT6															   *
* 19.02.2019 � Frederinn															   *
************************************************************************************************

*/


// Defines
#define		TempLog_Label_Filenumber	7												// Temperaturlogger Label Filenumber
#define		TempLog_Temp_Filenumber		8												// Temperaturlogger Data Filenumber
#define		F_CPU_Init					102000000UL
#define 	F_CPU 						168000000UL
#define 	SPI_Clockdiv_default 		_2
#define 	SPI_Default_Clockdivider 	2UL												// Default Clockteiler als Zahl, 4UL, 8UL, .. 256UL

#define NVIC_PRIORITYGROUP_0         0x00000007U /*!< 0 bits for pre-emption priority
                                                      4 bits for subpriority */
#define NVIC_PRIORITYGROUP_1         0x00000006U /*!< 1 bits for pre-emption priority
                                                      3 bits for subpriority */
#define NVIC_PRIORITYGROUP_2         0x00000005U /*!< 2 bits for pre-emption priority
                                                      2 bits for subpriority */
#define NVIC_PRIORITYGROUP_3         0x00000004U /*!< 3 bits for pre-emption priority
                                                      1 bits for subpriority */
#define NVIC_PRIORITYGROUP_4         0x00000003U /*!< 4 bits for pre-emption priority
                                                      0 bits for subpriority */


#define _2			0
#define _4			1
#define _8			2
#define _16			3
#define _32			4
#define _64     	5
#define _128    	6
#define _256		7


// Structs
struct Webserver
{
	char IP_address[4];																	// IP Adresse des Server
	char Subnetmask[4];																	// Subnetzmaske
	char Gateway_IP[4];																	// Gateway Adresse
	char MAC[6];																		// MAC Adresse
	char NTP_IP[4];																		// NTP IP
};


// Variablen
extern struct Webserver gl_Webserver;													// Globale von Webserver

// Funktionen
extern int main(void);																	// Main Loop
extern void Main_Init_Tasktimer(void);													// Tasktimer einstellen
extern void Main_Read_Timestamp(void);													// Zeitstempel lesen
extern void Main_Genie_refresh(void);													// Display aktualisieren
extern void Main_Temperaturelogger(void);												// Temperaturmessung des DS18B20
extern void Main_Stack_Packetloop_stuff(void);

//Wenn die Funktion direkt nach dem einstellen der CPU Frequenz passiert, kann es durch die Optimierung passieren,
//dass dieser Wartebefehl zu lange dauert. Im weiteren Programmverlauf stimmts dann
static inline void _delay_us(double micros) __attribute__ ((always_inline));			// Delay us
static inline void _delay_us_init(double micros) __attribute__ ((always_inline));

void _delay_us(double micros)
{
	uint32_t wait = (unsigned int)(fabs(micros * ((0.000001/(1.0/F_CPU))/3.0)));			// Die delay_loop sollte 3 Ticks brauchen, deswegen die 3
	if(wait==0){wait=1;}

	asm volatile(
	"ldr r3, %[tick];"
	"1:"
	"subs r3,r3,#1;"
	"bne.n 1b;"
	:
	: [tick] "m" (wait)
	: "r3");
}

void _delay_us_init(double micros)
{
	uint32_t wait = (unsigned int)(fabs(micros * ((0.000001/(1.0/F_CPU_Init))/3.0)));		// Die delay_loop sollte 3 Ticks brauchen, deswegen die 3
	if(wait==0){wait=1;}

	asm volatile(
	"ldr r3, %[tick];"
	"1:"
	"subs r3,r3,#1;"
	"bne.n 1b;"
	:
	: [tick] "m" (wait)
	: "r3");
}



#endif /* MAIN_H_ */
